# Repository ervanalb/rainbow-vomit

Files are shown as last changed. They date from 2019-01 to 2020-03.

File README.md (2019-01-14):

# Rainbow Vomit
The stupid simple WS2812 driver

## Why?
I wanted to drive WS2812 LEDs from a computer. For some reason that's not a solved problem?

## What?
Pixels get clocked at 800 kbps, and each pixel is 24 bits.
If you want a 30 Hz refresh rate, you should be able to drive smooth video to a strand of 1024 pixels.

I want a USB interface, and USB FS can do 12 mbps. So that means I should be able to run about 8 channels at 800 kbps with some room for overhead.

So I should be able to run smooth video on a 8192 LED setup without even diving into high speed USB.

For some reason, most simple drivers can't come close to these specs. Respect for the [Pixel Pusher](http://www.heroicrobotics.com/products/pixelpusher) though, it's just large, expensive, and uses Ethernet.

## How?
I tricked the STM32F105 into doing this for me. It took a lot of fiddling with the DMA engine and USB peripheral. It's an extension of the approach [here](https://github.com/ervanalb/lux/blob/master/led_strip_firmware/app/src/ws2811_strip.c) to 8 channels (all four channels on two timers.)

I've included a [binary](driver-firmware/rainbow-vomit-driver.bin) in the git repository because the timing is very finicky and you may not get full speed on your compiler.

## Anything else?
Why yes, thanks for asking.

You may not want your display topology to require daisy-chaining LEDs together until you reach 1000 pixels.
So, I'm going to make a multiplexer board that splits a single channel into N strips.
It will distribute pixels round-robin to all the connected strips so you can use more of a star topology in your setup.
This will operate entirely on the WS2812 protocol, so you can use any driver, not just mine.

I also find it weird that this doesn't exist yet.

## Now what?
Maybe Adafruit or Sparkfun will steal my design and mass produce it. That would be cool.

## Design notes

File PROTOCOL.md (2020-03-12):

# Protocol

## USB protocol
The LED strip driver enumerates as a virtual serial port.

Each frame consists of a 16-byte chunk of metadata, followed by the pixel data. The metadata must be sent every frame, and contains the length for each channel.
The lengths are little-endian and are in bytes, so multiply the number of RGB pixels you have by 3.

Metadata format:

<table>
 <tr><td>Channel 0 length LSB</td></tr>
 <tr><td>Channel 0 length MSB</td></tr>
 <tr><td>Channel 1 length LSB</td></tr>
 <tr><td>Channel 1 length MSB</td></tr>
 <tr><td>...</td></tr>
 <tr><td>Channel 7 length LSB</td></tr>
 <tr><td>Channel 7 length MSB</td></tr>
</table>

Immediately following the metadata is the pixel data in the following format:

<table>
 <tr><td>Channel 0 byte 0 *(e.g. LED 0 Red)*</td></tr>
 <tr><td>Channel 0 byte 1 *(e.g. LED 0 Green)*</td></tr>
 <tr><td>Channel 0 byte 2 *(e.g. LED 0 Blue)*</td></tr>
 <tr><td>Channel 0 byte 3 *(e.g. LED 1 Red)*</td></tr>
 <tr><td>Channel 0 byte 4 *(e.g. LED 1 Green)*</td></tr>
 <tr><td>Channel 0 byte 5 *(e.g. LED 1 Blue)*</td></tr>
 <tr><td>...</td></tr>
 <tr><td>Channel 0 byte (Channel 0 length - 3)</td></tr>
 <tr><td>Channel 0 byte (Channel 0 length - 2)</td></tr>
 <tr><td>Channel 0 byte (Channel 0 length - 1)</td></tr>
 <tr><td>Channel 1 byte 0</td></tr>
 <tr><td>Channel 1 byte 1</td></tr>
 <tr><td>Channel 1 byte 2</td></tr>
 <tr><td>...</td></tr>
 <tr><td>Channel 7 byte (Channel 0 length - 1)</td></tr>
 <tr><td>Channel 7 byte (Channel 0 length - 1)</td></tr>
 <tr><td>Channel 7 byte (Channel 0 length - 1)</td></tr>
</table>

Once the predetermined amount of data has been received,
the frame will begin to be written out to the LED strips.

If the protocol gets out of sync, simply frob any control line of the serial port, for example, RTS. Closing and re-opening the serial port should also work.

## SD card protocol
The LED strip driver has an microSD card slot. It can read cards with a FAT filesystem. Right now it only looks for the `leds.dat` file.

The file follows the same protocol as above, but with the addition of a 2-byte frame time in milliseconds prepended to the metadata.

<table>
 <tr><td>Frame time LSB</td></tr>
 <tr><td>Frame time MSB</td></tr>
 <tr><td>16 byte metadata *(see above)*</td></tr>
 <tr><td>Pixel data *(see above)*</td></tr>
</table>

The frame time is unsigned and ranges from 0 ms - 65534 ms.
Setting the frame time to 65535 indicates that the frame should be shown indefinitely.
Setting the frame time to 0 indicates that the frame should be shown for as little time as possible.
Depending on the quantity of data, the board may not be able to keep up with the requested frame rate.
Frames that last longer than 60 seconds are possible by sending subsequent empty frames (0 bytes on every channel).
When the end of the file is reached, it will loop. To prevent this behavior, set the last frame time to 65535.

## Frame buffers
The output is double-buffered, so reception of a new frame command can be started immediately while the previous frame is being output.
If data reception of the second frame finishes before the first frame is done being output, the device will pause to allow output to finish. USB communication will be stalled during this time period
to ensure that a third frame is not received until there is a place to put it. In this way, the device will self rate-limit to the
maximum achievable framerate.

Each frame buffer has a maximum size of **24576 bytes**. You may split these bytes however you wish amongst the eight channels.
For instance, you could put them all towards channel 0 in which case you could drive 8192 24-bit RGB LEDs, but would be limited to about 4 frames per second.
Or, you could use 1024 pixels per channel, which would allow you to run at 30 FPS. Requesting more than the maximum number of bytes will result in undefined behavior.

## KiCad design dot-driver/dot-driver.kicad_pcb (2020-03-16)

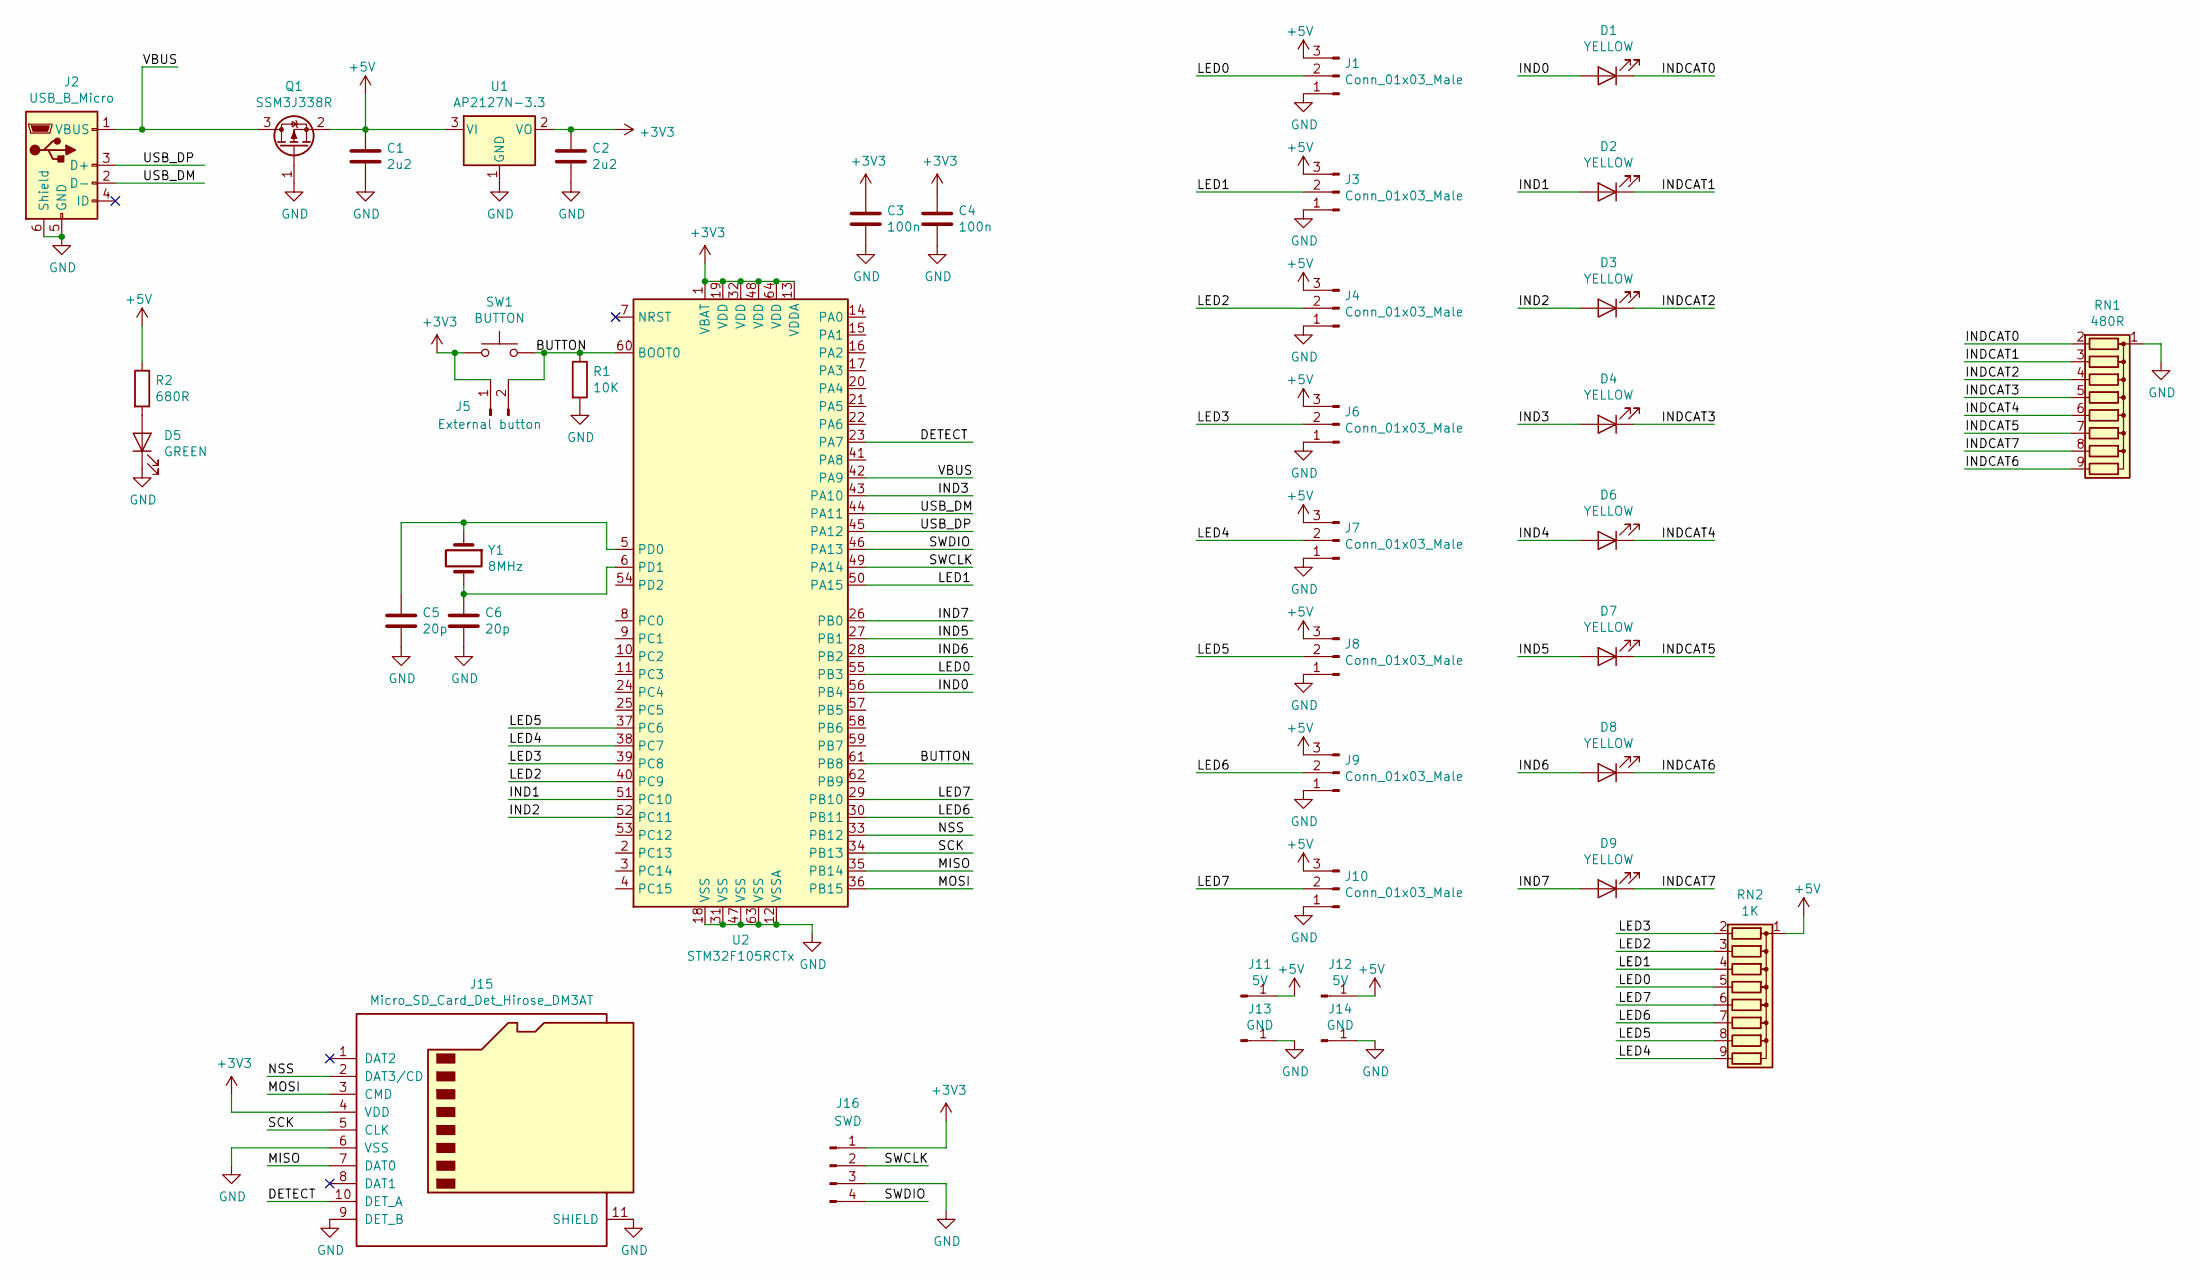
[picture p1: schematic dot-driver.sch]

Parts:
C1, C2: 2u2; C_0603
C3, C4: 100n; C_0603
C5, C6: 20p; C_0603
D1, D2, D3, D4, D6, D7, D8, D9: YELLOW; LED_0603
D5: GREEN; LED_0603
J1, J3, J4, J6, J7, J8, J9, J10: Conn_01x03_Male; Pin_Header_Straight_1x03
J2: USB_B_Micro; USB_Micro-B
J5: External button; Pin_Header_Straight_1x02
J11, J12: 5V; Pin_Header_Straight_1x01
J13, J14: GND; Pin_Header_Straight_1x01
J15: Micro_SD_Card_Det_Hirose_DM3AT; microSD_HC_Hirose_DM3AT-SF-PEJM5
J16: SWD; Pin_Header_Straight_1x04
Q1: SSM3J338R; SOT-23
R1: 10K; R_0603
R2: 680R; R_0603
RN1: 480R; R_Array_Convex_5x0603
RN2: 1K; R_Array_Convex_5x0603
SW1: BUTTON; SW_SPST_TL3342
U1: AP2127N-3.3; SOT-23
U2: STM32F105RCTx; LQFP-64_10x10mm_Pitch0.5mm
Y1: 8MHz; Crystal_SMD_5032_4Pads

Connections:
+3V3: C2.1, C3.1, C4.1, J5.1, J15.4 (VDD), J16.1, SW1.1, U1.2 (VO), U2.1 (VBAT), U2.13 (VDDA), U2.19 (VDD), U2.32 (VDD), U2.48 (VDD), U2.64 (VDD)
+5V: C1.1, J1.3, J3.3, J4.3, J6.3, J7.3, J8.3, J9.3, J10.3, J11.1, J12.1, Q1.2 (S), R2.1, RN2.1 (common), U1.3 (VI)
/BUTTON: J5.2, R1.1, SW1.2, U2.60 (BOOT0), U2.61 (PB8)
/DETECT: J15.10 (DET_A), U2.23 (PA7)
/IND0: D1.2 (A), U2.56 (PB4)
/IND1: D2.2 (A), U2.51 (PC10)
/IND2: D3.2 (A), U2.52 (PC11)
/IND3: D4.2 (A), U2.43 (PA10)
/IND4: D6.2 (A)
/IND5: D7.2 (A), U2.27 (PB1)
/IND6: D8.2 (A), U2.28 (PB2)
/IND7: D9.2 (A), U2.26 (PB0)
/INDCAT0: D1.1 (K), RN1.2 (R1)
/INDCAT1: D2.1 (K), RN1.3 (R2)
/INDCAT2: D3.1 (K), RN1.4 (R3)
/INDCAT3: D4.1 (K), RN1.5 (R4)
/INDCAT4: D6.1 (K), RN1.6 (R5)
/INDCAT5: D7.1 (K), RN1.7 (R6)
/INDCAT6: D8.1 (K), RN1.9 (R8)
/INDCAT7: D9.1 (K), RN1.8 (R7)
/LED0: J1.2, RN2.5 (R4), U2.55 (PB3)
/LED1: J3.2, RN2.4 (R3), U2.50 (PA15)
/LED2: J4.2, RN2.3 (R2), U2.40 (PC9)
/LED3: J6.2, RN2.2 (R1), U2.39 (PC8)
/LED4: J7.2, RN2.9 (R8), U2.38 (PC7)
/LED5: J8.2, RN2.8 (R7), U2.37 (PC6)
/LED6: J9.2, RN2.7 (R6), U2.30 (PB11)
/LED7: J10.2, RN2.6 (R5), U2.29 (PB10)
/MISO: J15.7 (DAT0), U2.35 (PB14)
/MOSI: J15.3 (CMD), U2.36 (PB15)
/NSS: J15.2 (DAT3/CD), U2.33 (PB12)
/SCK: J15.5 (CLK), U2.34 (PB13)
/SWCLK: J16.2, U2.49 (PA14)
/SWDIO: J16.4, U2.46 (PA13)
/USB_DM: J2.2 (D-), U2.44 (PA11)
/USB_DP: J2.3 (D+), U2.45 (PA12)
/VBUS: J2.1 (VBUS), Q1.3 (D), U2.42 (PA9)
GND: C1.2, C2.2, C3.2, C4.2, C5.2, C6.2, D5.1 (K), J1.1, J2.5 (GND), J2.6 (Shield), J3.1, J4.1, J6.1, J7.1, J8.1, J9.1, J10.1, J13.1, J14.1, J15.6 (VSS), J15.9 (DET_B), J15.11 (SHIELD), J16.3, Q1.1 (G), R1.2, RN1.1 (common), U1.1 (GND), U2.12 (VSSA), U2.18 (VSS), U2.31 (VSS), U2.47 (VSS), U2.63 (VSS)
unnamed: C5.1, U2.5 (PD0), Y1.1
unnamed: C6.1, U2.6 (PD1), Y1.2
unnamed: D5.2 (A), R2.2

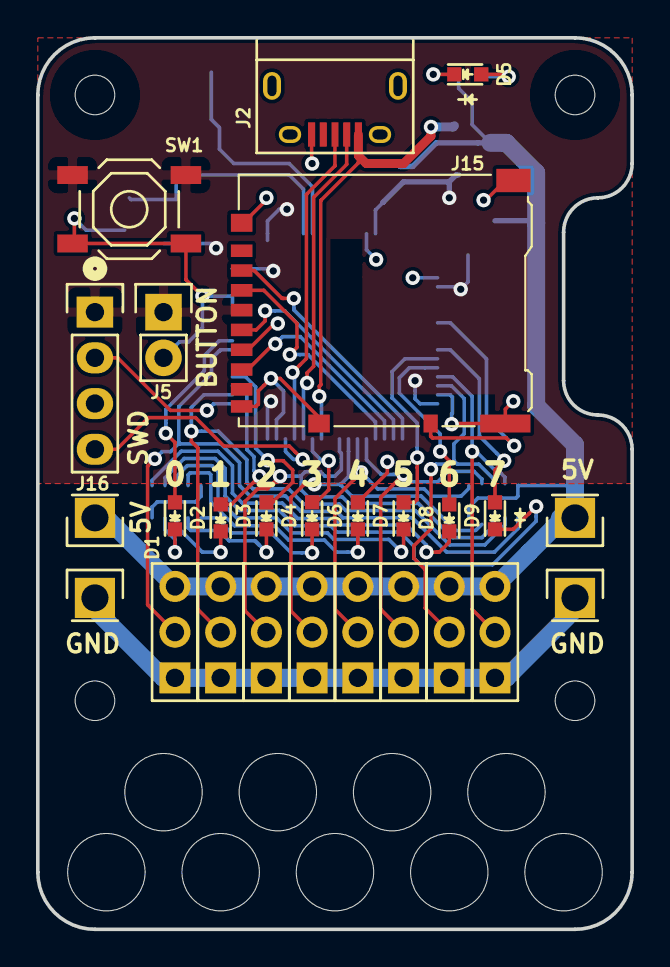
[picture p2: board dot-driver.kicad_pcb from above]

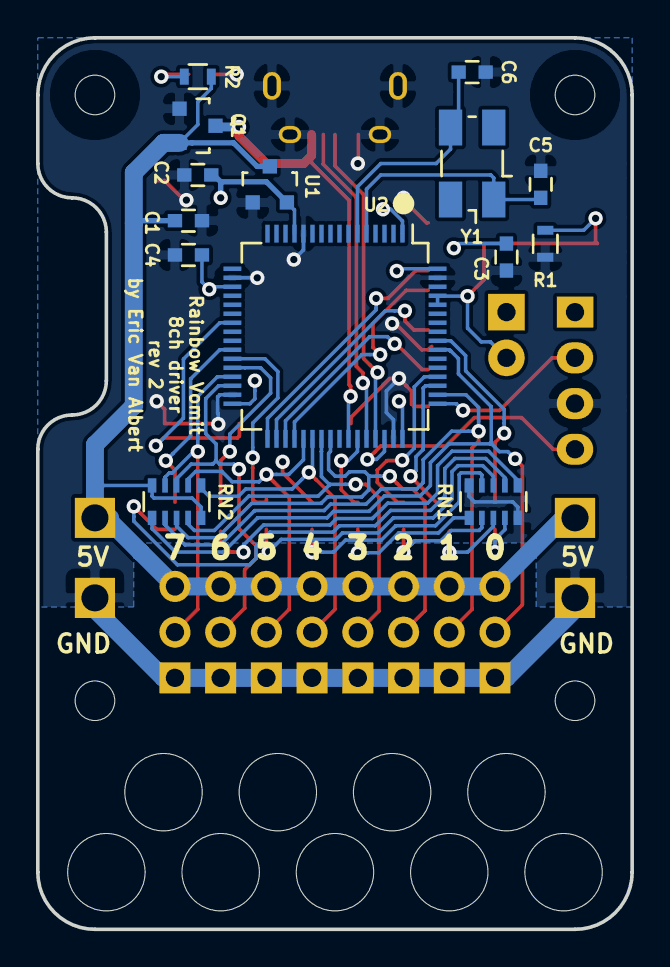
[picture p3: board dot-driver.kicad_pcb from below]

Board: 2 copper layers, 33.0 x 49.5 mm, 40 parts (14 on the bottom side), 40 nets.

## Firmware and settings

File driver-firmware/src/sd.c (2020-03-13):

// This is the low-level SD card driver
// It implements the functions necessary for ChaN's FatFS to work.
// See autorun.c for high-level SD card functionality

#include <libopencm3/stm32/rcc.h>
#include <libopencm3/stm32/gpio.h>
#include <libopencm3/stm32/spi.h>
#include <stdint.h>

enum sd_speed { SD_SPEED_400KHZ, SD_SPEED_25MHZ };

static void spi_set_speed(enum sd_speed speed) {
    rcc_periph_clock_enable(RCC_SPI1);
    gpio_set_mode(GPIOA, GPIO_MODE_OUTPUT_50_MHZ, GPIO_CNF_OUTPUT_ALTFN_PUSHPULL, GPIO4 | GPIO5 | GPIO7);
    gpio_set_mode(GPIOA, GPIO_MODE_INPUT, GPIO_CNF_INPUT_FLOAT, GPIO6);
    spi_reset(SPI1);

    spi_enable_software_slave_management(SPI1);
    spi_enable_ss_output(SPI1);

    uint32_t br = SPI_CR1_BAUDRATE_FPCLK_DIV_256;
    switch (speed) {
        case SD_SPEED_25MHZ:
            br = SPI_CR1_BAUDRATE_FPCLK_DIV_4;
            break;
        case SD_SPEED_400KHZ:
            break;
    }

    spi_init_master(SPI1, br, SPI_CR1_CPOL_CLK_TO_0_WHEN_IDLE,
                    SPI_CR1_CPHA_CLK_TRANSITION_1, SPI_CR1_DFF_8BIT, SPI_CR1_MSBFIRST);
    spi_enable(SPI1);
}

static uint8_t spi_txrx(uint8_t data) {
	SPI_DR(SPI1) = data;

	// Wait for transfer finished
    do {
        // These NOPs are critically important!
        // Busy-polling the SPI peripheral without them consumes too much memory bandwidth on the AHB.
        // This causes the DMA to the timer peripherals to miss cycles, leading to data corruption on the LEDs.
        // Ideally, we would put exactly as many here as are necessary to prevent the loop's exit condition from ever being true,
        // which would reduce AHB usage as much as possible.
        __asm__ volatile ("mov r0, r0");
        __asm__ volatile ("mov r0, r0");
        __asm__ volatile ("mov r0, r0");
        __asm__ volatile ("mov r0, r0");
        __asm__ volatile ("mov r0, r0");
        __asm__ volatile ("mov r0, r0");
        __asm__ volatile ("mov r0, r0");
    } while (!(SPI_SR(SPI1) & SPI_SR_RXNE));

	// Read the data
	return SPI_DR(SPI1);
}

static inline __attribute__((always_inline)) void spi_tx_16(uint16_t data) {
	SPI_DR(SPI1) = data;
}

static inline __attribute__((always_inline)) uint16_t spi_rx_16(void) {
	// Wait for transfer finished
    do {
        // These NOPs are critically important!
        // Busy-polling the SPI peripheral without them consumes too much memory bandwidth on the AHB.
        // This causes the DMA to the timer peripherals to miss cycles, leading to data corruption on the LEDs.
        // Ideally, we would put exactly as many here as are necessary to prevent the loop's exit condition from ever being true,
        // which would reduce AHB usage as much as possible.
        __asm__ volatile ("mov r0, r0");
        __asm__ volatile ("mov r0, r0");
        __asm__ volatile ("mov r0, r0");
        __asm__ volatile ("mov r0, r0");
        __asm__ volatile ("mov r0, r0");
        __asm__ volatile ("mov r0, r0");
        __asm__ volatile ("mov r0, r0");
    } while (!(SPI_SR(SPI1) & SPI_SR_RXNE));

	// Read the data
	return SPI_DR(SPI1);
}

static inline __attribute__((always_inline)) uint16_t spi_rxtx_16(uint16_t data) {
	// Wait for transfer finished
    do {
        // These NOPs are critically important!
        // Busy-polling the SPI peripheral without them consumes too much memory bandwidth on the AHB.
        // This causes the DMA to the timer peripherals to miss cycles, leading to data corruption on the LEDs.
        // Ideally, we would put exactly as many here as are necessary to prevent the loop's exit condition from ever being true,
        // which would reduce AHB usage as much as possible.
        __asm__ volatile ("mov r0, r0");
        __asm__ volatile ("mov r0, r0");
        __asm__ volatile ("mov r0, r0");
        __asm__ volatile ("mov r0, r0");
        __asm__ volatile ("mov r0, r0");
        __asm__ volatile ("mov r0, r0");
        __asm__ volatile ("mov r0, r0");
    } while (!(SPI_SR(SPI1) & SPI_SR_RXNE));

    // TX a new word ASAP
	SPI_DR(SPI1) = data;

	// Read the data
	return SPI_DR(SPI1);
}

static void spi_txrx_many(uint8_t *data, int len) {
    spi_set_dff_16bit(SPI1);

    int i;
    spi_tx_16(0xffff);
    for (i=0; i<len-3; i+=2) {
        uint16_t v = spi_rx_16();
        spi_tx_16(0xffff);
        data[i + 0] = v >> 8;
        data[i + 1] = v & 0xFF;
    }
    uint16_t v = spi_rx_16();
    data[i++] = v >> 8;
    data[i++] = v & 0xFF;

    spi_set_dff_8bit(SPI1);

    if (i < len) {
        data[i] = spi_txrx(0xff);
    }
}

static void spi_cs_low(void) {
    spi_set_nss_low(SPI1);
}

static void spi_cs_high(void) {
    spi_set_nss_high(SPI1);
}


/*
 * (c) Domen Puncer, Visionect, d.o.o.
 * BSD License
 *
 * v0.2 add support for SDHC
 *
 * Modified by Eric Van Albert
 */

#define printf(...)
#define u8 uint8_t
#define u16 uint16_t
#define u32 uint32_t

/*
 * Code is split into 2 parts:
 * - sd card code, with crc7 and crc16 calculations
 *   there's lots of it, but it's simple
 * - fatfs interface. If you use anything else, look here for
 *   interface to SD card code
 */

struct hwif {
	int initialized;
	int sectors;
	int erase_sectors;
	int capabilities;
};
typedef struct hwif hwif;

#define CAP_VER2_00	(1<<0)
#define CAP_SDHC	(1<<1)

/* crc helpers */
static u8 crc7_one(u8 t, u8 data)
{
	int i;
	const u8 g = 0x89;

	t ^= data;
	for (i=0; i<8; i++) {
		if (t & 0x80)
			t ^= g;
		t <<= 1;
	}
	return t;
}

//static u8 crc7(const u8 *p, int len)
//{
//	int j;
//	u8 crc = 0;
//	for (j=0; j<len; j++)
//		crc = crc7_one(crc, p[j]);
//
//	return crc>>1;
//}

/* http://www.eagleairaust.com.au/code/crc16.htm */
static u16 crc16_ccitt(u16 crc, u8 ser_data)
{
	crc  = (u8)(crc >> 8) | (crc << 8);
	crc ^= ser_data;
	crc ^= (u8)(crc & 0xff) >> 4;
	crc ^= (crc << 8) << 4;
	crc ^= ((crc & 0xff) << 4) << 1;

	return crc;
}

static u16 crc16(const u8 *p, int len)
{
	int i;
	u16 crc = 0;

	for (i=0; i<len; i++)
		crc = crc16_ccitt(crc, p[i]);

	return crc;
}


/*** sd functions - on top of spi code ***/

static void sd_cmd(u8 cmd, u32 arg)
{
	u8 crc = 0;
	spi_txrx(0x40 | cmd);
	crc = crc7_one(crc, 0x40 | cmd);
	spi_txrx(arg >> 24);
	crc = crc7_one(crc, arg >> 24);
	spi_txrx(arg >> 16);
	crc = crc7_one(crc, arg >> 16);
	spi_txrx(arg >> 8);
	crc = crc7_one(crc, arg >> 8);
	spi_txrx(arg);
	crc = crc7_one(crc, arg);
	//spi_txrx(0x95);	/* crc7, for cmd0 */
	spi_txrx(crc | 0x1);	/* crc7, for cmd0 */
}

static u8 sd_get_r1(void)
{
	int tries = 1000;
	u8 r;

	while (tries--) {
		r = spi_txrx(0xff);
		if ((r & 0x80) == 0)
			return r;
	}
	return 0xff;
}

static u16 sd_get_r2(void)
{
	int tries = 1000;
	u16 r;

	while (tries--) {
		r = spi_txrx(0xff);
		if ((r & 0x80) == 0)
			break;
	}
	if (tries < 0)
		return 0xff;
	r = r<<8 | spi_txrx(0xff);

	return r;
}
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

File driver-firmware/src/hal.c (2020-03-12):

#include <libopencm3/stm32/rcc.h>
#include <libopencm3/stm32/gpio.h>
#include <libopencm3/usb/usbd.h>
#include <libopencm3/usb/cdc.h>
#include <libopencm3/stm32/dma.h>
#include <libopencm3/cm3/nvic.h>
#include <libopencm3/cm3/scb.h>
#include <libopencm3/lib/usb/usb_private.h>
#include <libopencm3/cm3/systick.h>
#include <stddef.h>

// This hack gets us access to
// stm32f107_usbd_init
// which is necessary for initializing the struct below
#include <libopencm3/lib/usb/usb_f107.c>

// Expand the FIFO size of the USB driver
static const struct _usbd_driver custom_usb_driver = {
    .init = stm32f107_usbd_init,
    .set_address = dwc_set_address,
    .ep_setup = dwc_ep_setup,
    .ep_reset = dwc_endpoints_reset,
    .ep_stall_set = dwc_ep_stall_set,
    .ep_stall_get = dwc_ep_stall_get,
    .ep_nak_set = dwc_ep_nak_set,
    .ep_write_packet = dwc_ep_write_packet,
    .ep_read_packet = dwc_ep_read_packet,
    .poll = dwc_poll,
    .disconnect = dwc_disconnect,
    .base_address = USB_OTG_FS_BASE,
    .set_address_before_status = 1,
    .rx_fifo_size = 224,
};

#include "hal.h"
#include "protocol.h"

static const uint32_t LED_GPIOS[] = {
    GPIOC,
    GPIOC,
    GPIOC,
    GPIOA,
    GPIOB,
    GPIOB,
    GPIOB,
    GPIOB
};

static const uint16_t LED_PINS[] = {
    GPIO12,
    GPIO11,
    GPIO10,
    GPIO10,
    GPIO15,
    GPIO14,
    GPIO13,
    GPIO12
};

void hal_set_led(int which) {
    gpio_set(LED_GPIOS[which], LED_PINS[which]);
}

void hal_clear_led(int which) {
    gpio_clear(LED_GPIOS[which], LED_PINS[which]);
}

static const struct usb_device_descriptor dev = {
  .bLength = USB_DT_DEVICE_SIZE,
  .bDescriptorType = USB_DT_DEVICE,
  .bcdUSB = 0x0200,
  .bDeviceClass = USB_CLASS_CDC,
  .bDeviceSubClass = 0,
  .bDeviceProtocol = 0,
  .bMaxPacketSize0 = 64,
  .idVendor = 0x0483,
  .idProduct = 0x5740,
  .bcdDevice = 0x0200,
  .iManufacturer = 1,
  .iProduct = 2,
  .iSerialNumber = 3,
  .bNumConfigurations = 1,
};

/*
 * This notification endpoint isn't implemented. According to CDC spec its
 * optional, but its absence causes a NULL pointer dereference in Linux
 * cdc_acm driver.
 */
static const struct usb_endpoint_descriptor comm_endp[] = {
  {
    .bLength = USB_DT_ENDPOINT_SIZE,
    .bDescriptorType = USB_DT_ENDPOINT,
    .bEndpointAddress = 0x83,
    .bmAttributes = USB_ENDPOINT_ATTR_INTERRUPT,
    .wMaxPacketSize = 16,
    .bInterval = 255,
  }
};

static const struct usb_endpoint_descriptor data_endp[] = {
  {
    .bLength = USB_DT_ENDPOINT_SIZE,
    .bDescriptorType = USB_DT_ENDPOINT,
    .bEndpointAddress = 0x01,
    .bmAttributes = USB_ENDPOINT_ATTR_BULK,
    .wMaxPacketSize = 64,
    .bInterval = 1,
  },
  {
    .bLength = USB_DT_ENDPOINT_SIZE,
    .bDescriptorType = USB_DT_ENDPOINT,
    .bEndpointAddress = 0x82,
    .bmAttributes = USB_ENDPOINT_ATTR_BULK,
    .wMaxPacketSize = 64,
    .bInterval = 1,
  }
};

static const struct {
  struct usb_cdc_header_descriptor header;
  struct usb_cdc_call_management_descriptor call_mgmt;
  struct usb_cdc_acm_descriptor acm;
  struct usb_cdc_union_descriptor cdc_union;
} __attribute__((packed)) cdcacm_functional_descriptors = {
  .header = {
    .bFunctionLength = sizeof(struct usb_cdc_header_descriptor),
    .bDescriptorType = CS_INTERFACE,
    .bDescriptorSubtype = USB_CDC_TYPE_HEADER,
    .bcdCDC = 0x0110,
  },
  .call_mgmt = {
    .bFunctionLength = 
    sizeof(struct usb_cdc_call_management_descriptor),
    .bDescriptorType = CS_INTERFACE,
    .bDescriptorSubtype = USB_CDC_TYPE_CALL_MANAGEMENT,
    .bmCapabilities = 0,
    .bDataInterface = 1,
  },
  .acm = {
    .bFunctionLength = sizeof(struct usb_cdc_acm_descriptor),
    .bDescriptorType = CS_INTERFACE,
    .bDescriptorSubtype = USB_CDC_TYPE_ACM,
    .bmCapabilities = 0,
  },
  .cdc_union = {
    .bFunctionLength = sizeof(struct usb_cdc_union_descriptor),
    .bDescriptorType = CS_INTERFACE,
    .bDescriptorSubtype = USB_CDC_TYPE_UNION,
    .bControlInterface = 0,
    .bSubordinateInterface0 = 1, 
  }
};

static const struct usb_interface_descriptor comm_iface[] = {
  {
    .bLength = USB_DT_INTERFACE_SIZE,
    .bDescriptorType = USB_DT_INTERFACE,
    .bInterfaceNumber = 0,
    .bAlternateSetting = 0,
    .bNumEndpoints = 1,
    .bInterfaceClass = USB_CLASS_CDC,
    .bInterfaceSubClass = USB_CDC_SUBCLASS_ACM,
    .bInterfaceProtocol = USB_CDC_PROTOCOL_AT,
    .iInterface = 0,
    .endpoint = comm_endp,
    .extra = &cdcacm_functional_descriptors,
    .extralen = sizeof(cdcacm_functional_descriptors)
  }
};

static const struct usb_interface_descriptor data_iface[] = {
  {
    .bLength = USB_DT_INTERFACE_SIZE,
    .bDescriptorType = USB_DT_INTERFACE,
    .bInterfaceNumber = 1,
    .bAlternateSetting = 0,
    .bNumEndpoints = 2,
    .bInterfaceClass = USB_CLASS_DATA,
    .bInterfaceSubClass = 0,
    .bInterfaceProtocol = 0,
    .iInterface = 0,
    .endpoint = data_endp,
  }
};

static const struct usb_interface ifaces[] = {
  {
    .num_altsetting = 1,
    .altsetting = comm_iface,
  },
  {
    .num_altsetting = 1,
    .altsetting = data_iface,
  }
};

static const struct usb_config_descriptor config = {
  .bLength = USB_DT_CONFIGURATION_SIZE,
  .bDescriptorType = USB_DT_CONFIGURATION,
  .wTotalLength = 0,
  .bNumInterfaces = 2,
  .bConfigurationValue = 1,
  .iConfiguration = 0,
  .bmAttributes = 0x80,
  .bMaxPower = 0x32,
  .interface = ifaces,
};

static const char *usb_strings[] = {
  "Black Sphere Technologies",
  "CDC-ACM Demo",
  "DEMO",
};

/* Buffer to be used for control requests. */
uint8_t usbd_control_buffer[128];

// Counter for SysTick
static volatile uint32_t timer;
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

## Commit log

2018-11-13 add schematics
    [dot-driver.kicad_pcb, dot-driver.sch]
2018-11-13 Add gerbers
    [dot-driver-B.Cu.gbr, dot-driver-B.Mask.gbr, dot-driver-B.Paste.gbr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]
2019-01-09 start working on output ability
    [dot-driver.sch]
2019-01-12 Fix DMA alignment problem
    [output.c, test.py]
2019-01-13 Fixed USB speed, now need to improve protocol decode speed
    [hal.c, protocol.c]
2020-03-07 Start adding SPI HAL
2020-03-07 Add ChaN's FatFS, and fix warnings
    [sd.c]
2020-03-12 Fix DMA AHB contention problems
    [output.c, sd.c]
2020-03-12 Move SD startup code to autorun.c, move indicator lights to interrupt, remove 1 NOP
2020-03-12 Add frame timing to SD card with systick
2020-03-13 Fix SD clock frequencies, and implement a slightly improved multi-byte transfer function
    [sd.c]
2020-03-15 Improve schematic and layout, but they are out of sync
    [dot-driver.kicad_pcb, dot-driver.sch]
2020-03-15 Route rev2 of driver board
    [dot-driver.kicad_pcb, dot-driver.sch]
2020-03-16 Generate rev2 gerbers
    [dot-driver-B.Cu.gbr, dot-driver-B.Mask.gbr, dot-driver-B.SilkS.gbr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]
